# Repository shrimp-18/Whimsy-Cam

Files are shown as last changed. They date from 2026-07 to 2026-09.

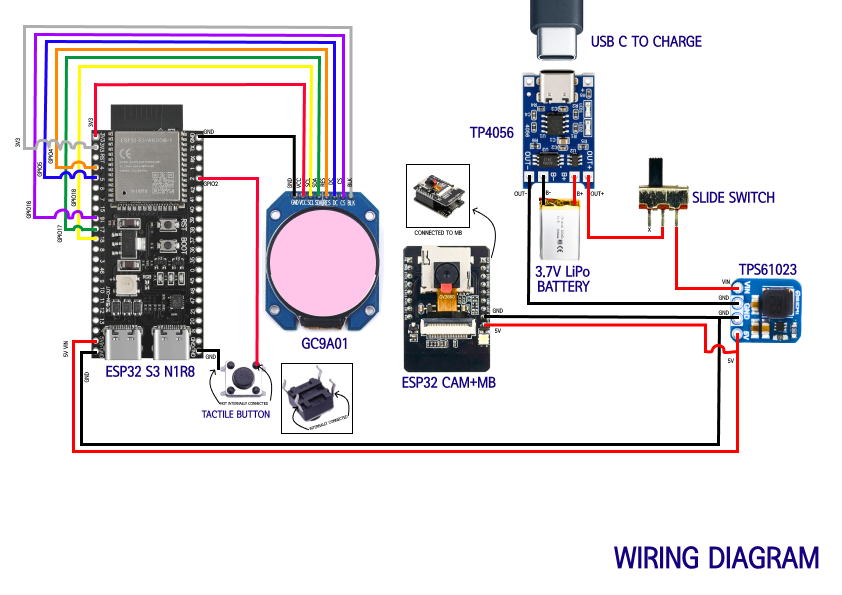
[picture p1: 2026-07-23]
images/wiringdiagram.png

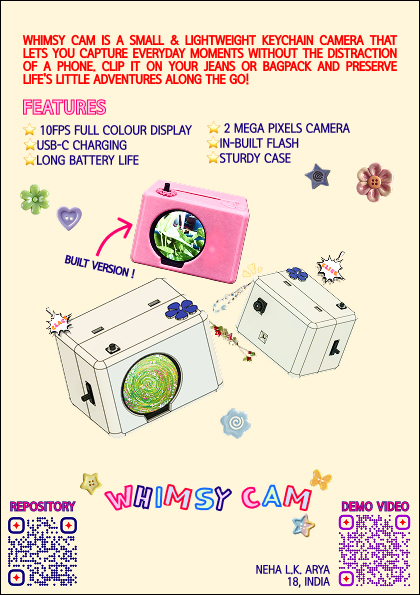
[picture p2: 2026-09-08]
images/zinenew.jpg

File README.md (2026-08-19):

# Whimsy-Cam

WhimsyCam is a small and lightweight keychain camera that lets you capture everyday moments without the distractions of a phone. Clip it to your keys, wear it anywhere, and preserve life's little adventures as they happen!

---

## Demo Video: [Link](https://youtu.be/K1ssOHKLGK0?si=9Yla5hCVhIQCYA2k_)

A5 - 1



**FEATURES** :
+ 2 MEGAPIXEL CAMERA
+ 10FPS FULL COLOUR DISPLAY
+ USB-C CHARGING
+ LONG BATTERY LIFE
+ IN-BUILT FLASH
+ KEYCHAIN/CHARM LANYARD HOLE
+ STURDY CASE
+ EASY SOFTWARE UPDATES

## How to Use:
Whimsy Cam is supa simple to use! Just charge it every once in a while, turn it on and click photos! It comes with s 64gb SD-Card, that means LOTSSSS of photos. It is designed to let you attach cute lanyards and charms to it :3 Keep checking this repository often! If there are updates, you can simply update the firmware of your camera too without touching the hardware or opening anything up. 




---

## Why I made this:
I love photography a lot! And with the recent rise in trend of the kodak keychain disposable camera, I wanted to make something of my own but more durable and long lasting. Whimsy Cam will cost you about 4.5k INR to make, but if you play your cards right(like I did) and use an SD card with lesser storage capacity, you could make it for almost half the price! Which is so much cheaper than whats commercially available, and so much versatile. On the same hardware, you have endless possibilities. In the future I plan to add filters for your photos and improved image quality! And you dont even need to de-assemble your camera to update to the latest software :D, just plug a USB C and hit upload!

---

## How the Camera works:
The Camera is divided into 2 main parts: The Camera Module and the Display Module.
1. The Camera Module:
   The Camera Module is made up of the ESP32 Camera Module with a GC2145 Sensor and an ESP32 Cam MB.It is a TCP(Transmission Control Protocol) Server. It establishes a        WiFi Server and send the captured about 8-10 frames per second to the TCP Client (the display module). When you click a photo, transmission stops for a tiny moment to      capture a high resolution photo and save it as a BMP file to the SD Card. This module gets power from 5V boosted LiPo Battery.
   
3. The Display Module:
   The Display Module is made up of the ESP 32 S3 N1R8 (dev board), a GC9A01 Circual TFT Screen and a tactile button. The ESP 32 S3 is a TCP Client, It recieves frames and    displays them on the screen. When the button is pressed it sends a command to click a photo.This module also gets 5V power from LiPo Battery (after boosting)

The Power Management: 



This wonderful diagram shows the power management of the Camera.
A re-chargable LiPo battery that outputs 3.7V is used. Since the ESP 32 modules need strictly either 3.3V or 5V, I used a TPS61023 Boost Converter to convert 3.7V to a stable 5V. There is a slide switch in between to turn the power on and off. The battery can also be recharged using the T4056 Module, I'm using a Type-C variant. This doesn't really have an over-charge or over-discharge protection yet :( But I'll think about it in future. Since the camera hardware cannot be changed so easily, I'll atleast add a battery level monitor on the camera display to at least protect it from over-discharge. And the green light from the T4056 can be your cue to stop charging hence acting as an over-charge protection.

---

## The Wiring Diagram:
wiringdiagram

## The Case:



----
## Fusion File:
https://a360.co/4wc3e6t

## How to Build:
So did I finally convince you to make your own :3 <br>
1.Procure all components listed in the BOM.<br>

2.Solder Pins to the Display Module.<br>

3.Get Jumper Wireeeess (you'll need 10) and a metre of normal wire. Copy the wiring diagram and connect everything. Try to use the colour-coded wires like I did. Its much easier to understand and remember!<br>

4.Download the code from the firmware folder inside src in this repository. Connect the ESP32 S3 and the Camera module to your computer. Download the Arduino IDE.Compile and upload the code to the respective boards! Now your camera should work!<br>

5.If youre using an SD Card, make sure its formatted to FAT and not ExFAT. Most SD cards by default will be formatted to ExFAT so you need to format them again using your laptop before you plug them into this camera for use. Otherwise your camera wont save photos :( <br>

6.The Fun Part! 3D-print the CAD Files(Front and Back of Case) given in this repository and fix the components in their respective places. Close the case shut! It is a snap fit case. <br>

7.Make cute lanyards and beaded chains to put on the camera so you can carry it around and be a cool kid. Cool because you have a keychain camera and because YOU MADE IT!<br>

YAY DAS IT ITS DONE
idea

---

## Bill of Materials

| S.No. | Product Name | Note | Qty | Cost (INR) | Link |
|---|---|---|-----|---|---|
| 1 | ESP32 S3 N16R8 | | 1 | 1249 | https://robocraze.com/products/7semi-esp32-s3-dev-boardc-1-n8r8-wifi-bluetooth-dual-usb-c-rgb-led |
| 2 | TPS61023 | | 1 | 109 | https://robocraze.com/products/tps61023-3-7a-5v-output-mini-boost-converter-breakout-board-7semi |
| 3 | TP4056 | | 1 | 19 | https://robocraze.com/products/tp4056-battery-charger-c-type-module-with-protection-1 |
| 4 | LiPo Battery | | 1 | 102 | https://robocraze.com/products/witty-fox-160mah-rechargeable-3-7v-lipo-battery |
| 5 | Slide Switch | | 1 | 16 | https://robocraze.com/products/slide-switch-3-pin-2-way-spdt |
| 6 | Tactile Button | 6x6mm | 1 | 29 | https://robocraze.com/products/4-pins-dip-momentary-square-tactile-push-button-switch-10-pieces-6x6x5mm |
| 7 | GC9A01 TFT Screen | | 1 | 422 | https://www.xcluma.com/1-28-inch-round-screen-tft-module-240x240-hd-ips-full |
| 8 | ESP32 Cam Module | GC2145 Sensor | 1 | 699 | https://quartzcomponents.com/products/esp32-camera-development-board-wifi-bluetooth-with-ov2640-camera-module |
| 9 | ESP32 Cam MB | | 1 | 82 | https://quartzcomponents.com/products/esp32-cam-mb-micro-usb-programmer-module-for-esp32-cam-development-board |
| 10 | SD Card | 64GB | 1 | 1605 | https://quartzcomponents.com/products/sandisk-ultra-64gb-microsdxc-class-10-memory-card-140mb-s |
| 11 | 3D Case - Back | | 1 | 95 | https://zbotic.in/product/online-3d-printing-service/ |
| 12 | 3D Case - Front | | 1 | 93 | https://zbotic.in/product/online-3d-printing-service/ |

**Total: 12 items — ₹4520 (~$47 USD)**

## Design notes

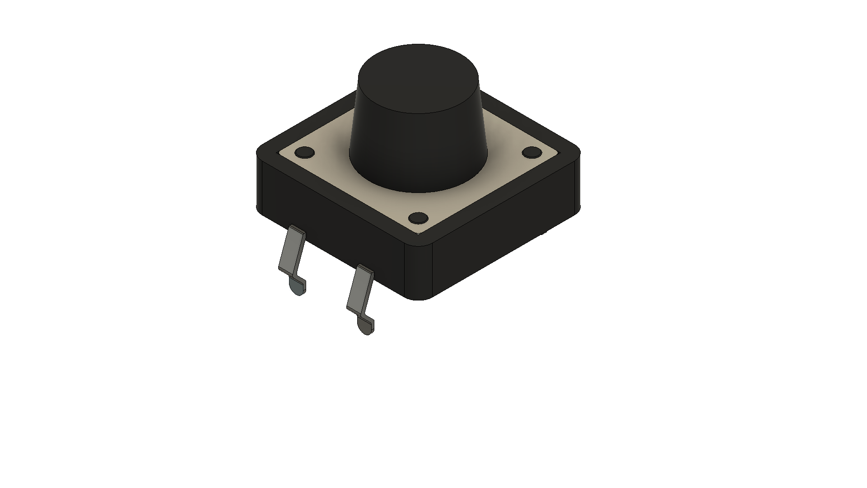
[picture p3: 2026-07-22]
src/cad/assets/12mm x 12mm Tactile switch 3D view.png

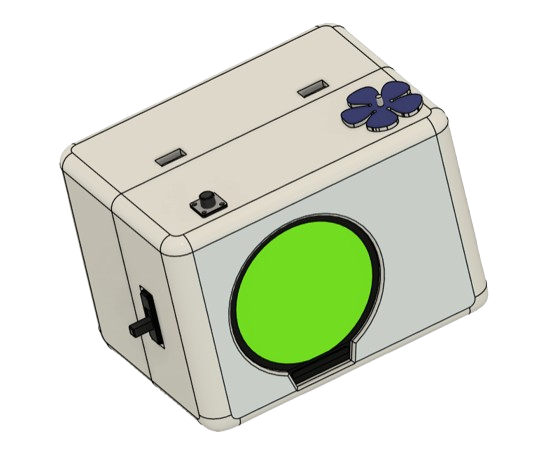
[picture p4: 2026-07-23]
images/camfront.png

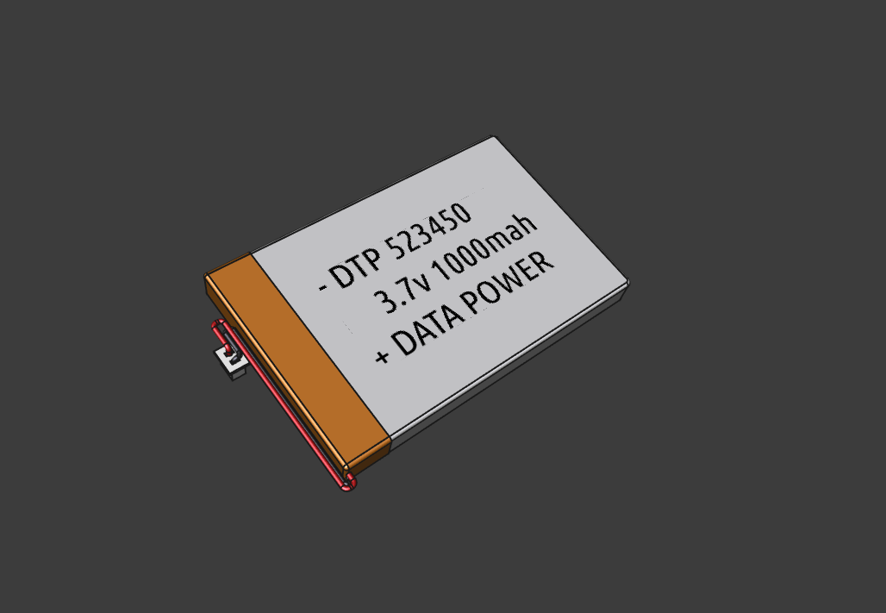
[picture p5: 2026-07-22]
src/cad/assets/bateria_litio.png

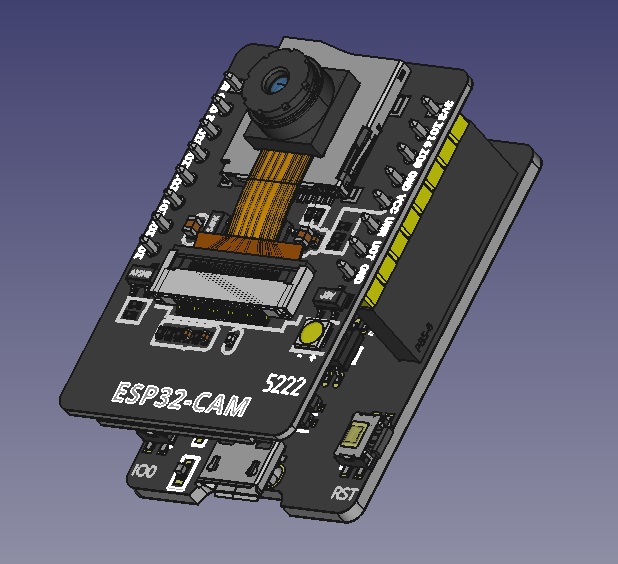
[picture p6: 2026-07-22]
src/cad/assets/View.jpg

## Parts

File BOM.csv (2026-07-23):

S. No. | Product Name | Note | Quantity | Cost | Link
1 | ESP32 S3 N1R8 |  | 1 | INR1249 | https://robocraze.com/products/7semi-esp32-s3-dev-boardc-1-n8r8-wifi-bluetooth-dual-usb-c-rgb-led
2 | TPS61023 |  | 1 | INR109 | https://robocraze.com/products/tps61023-3-7a-5v-output-mini-boost-converter-breakout-board-7semi
3 | TP4056 |  | 1 | INR19 | https://robocraze.com/products/tp4056-battery-charger-c-type-module-with-protection-1
4 | LiPo Battery |  | 1 | INR102 | https://robocraze.com/products/witty-fox-160mah-rechargeable-3-7v-lipo-battery
5 | Slide Switch |  | 1 | INR16 | https://robocraze.com/products/slide-switch-3-pin-2-way-spdt
6 | Tactile Button | 6x6mm | 1 | INR29 | https://robocraze.com/products/4-pins-dip-momentary-square-tactile-push-button-switch-10-pieces-6x6x5mm
7 | GC9A01 TFT Screen |  | 1 | INR422 | https://www.xcluma.com/1-28-inch-round-screen-tft-module-240x240-hd-ips-full
8 | ESP32 Cam Module | GC2145 Sensor | 1 | INR699 | https://quartzcomponents.com/products/esp32-camera-development-board-wifi-bluetooth-with-ov2640-camera-module
9 | ESP32 Cam MB |  | 1 | INR82 | https://quartzcomponents.com/products/esp32-cam-mb-micro-usb-programmer-module-for-esp32-cam-development-board
10 | SD Card | 64GB | 1 | INR1605 | https://quartzcomponents.com/products/sandisk-ultra-64gb-microsdxc-class-10-memory-card-140mb-s
11 | 3D Case-Back |  | 1 | INR95 | https://zbotic.in/product/online-3d-printing-service/
12 | 3D Case-Front |  | 1 | INR93 | https://zbotic.in/product/online-3d-printing-service/
 |  |  | Total: | 10 | INR4520
 |  |  |  |  | ~47USD

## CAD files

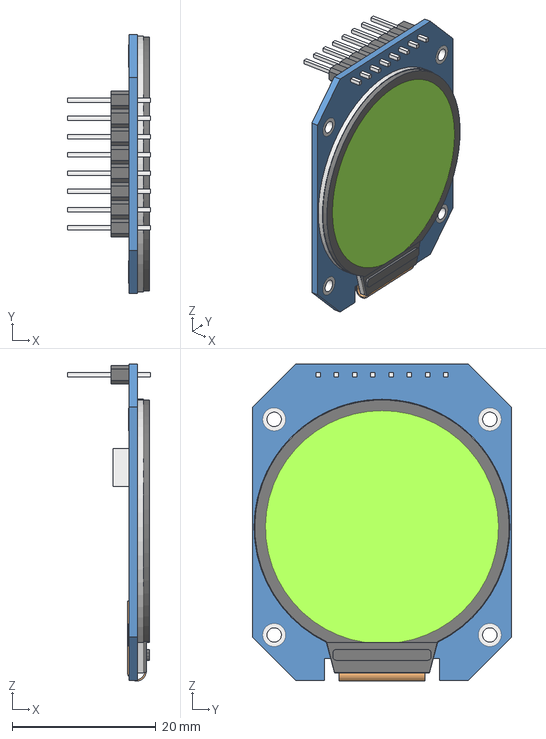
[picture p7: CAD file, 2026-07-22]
src/cad/assets/LCD 1.28 Inch GC9A01.stp
11.5 x 36.0 x 44.1 mm

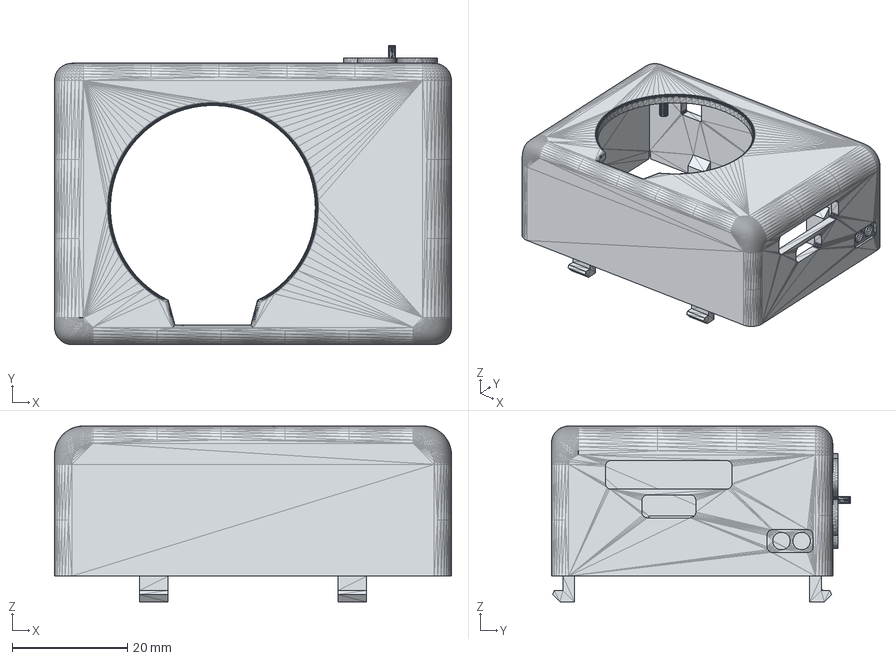
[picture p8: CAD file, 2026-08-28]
src/cad/Front.step
69.0 x 52.0 x 30.6 mm

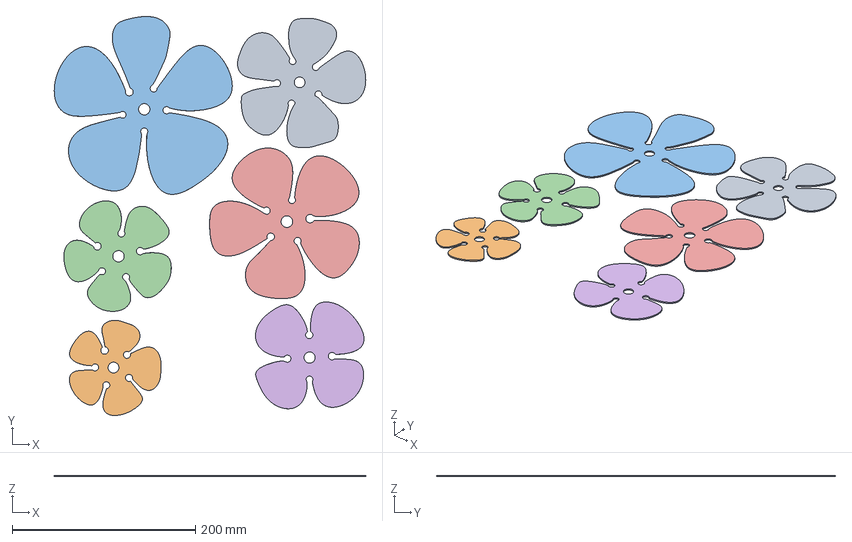
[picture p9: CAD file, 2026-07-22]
src/cad/assets/ROSE PETAL TEMPLATE_STEP.step
340.4 x 435.9 x 1.59 mm

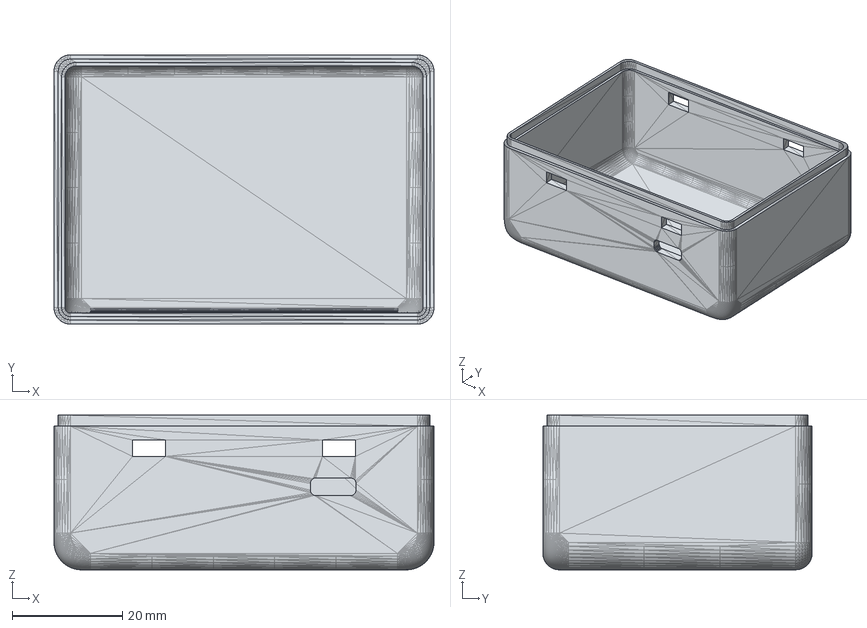
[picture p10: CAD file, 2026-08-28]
src/cad/Back.step
69.0 x 48.9 x 28.1 mm

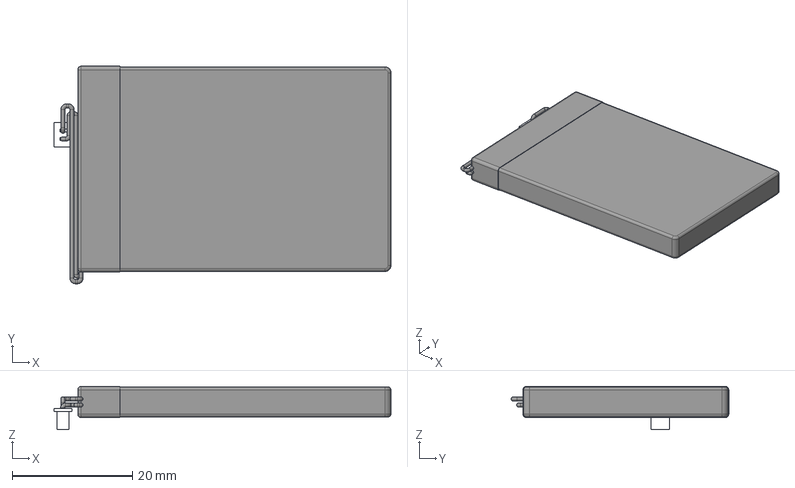
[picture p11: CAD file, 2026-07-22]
src/cad/assets/Litio_523450.step
56.0 x 36.2 x 7.20 mm
Conector

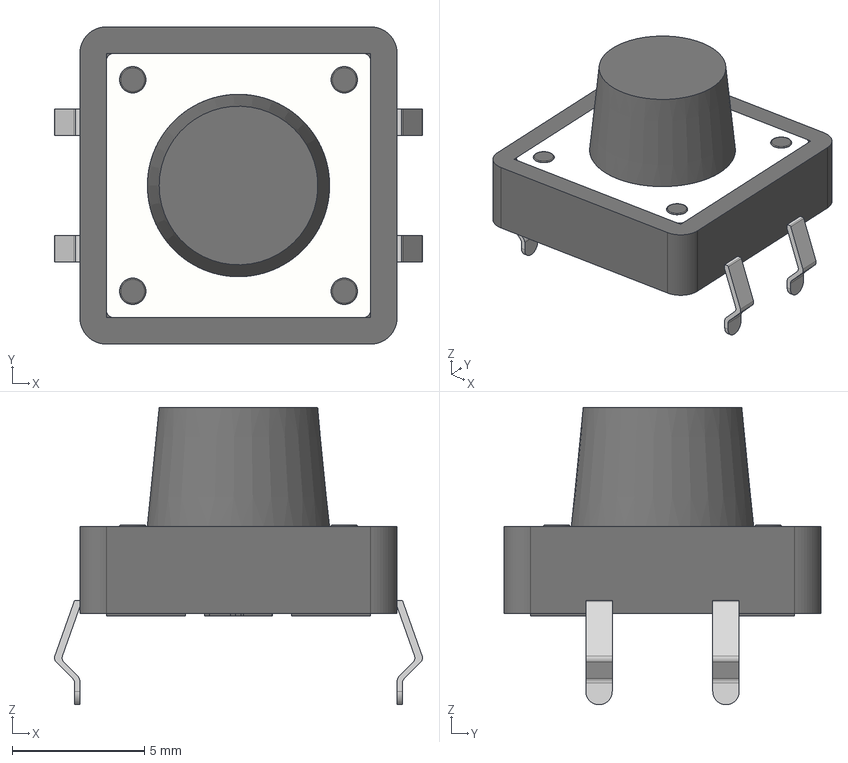
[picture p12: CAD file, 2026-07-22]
src/cad/assets/12mm x 12mm Tactile switch Button.step
13.9 x 12.0 x 11.2 mm
External Case
Steel Plate
Push Button

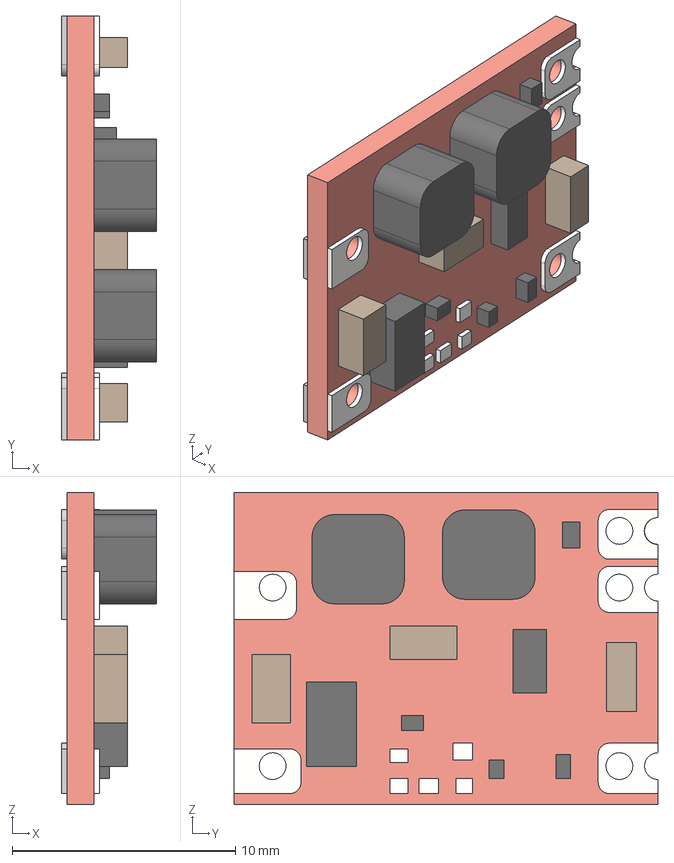
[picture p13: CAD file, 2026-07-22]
src/cad/assets/Auto Buck-Boost DC-DC Converter 12V~0.6A.step
4.25 x 19.0 x 14.0 mm
PCB
Coils
Capacitors
ICS
Resistors
Solder
Terminals

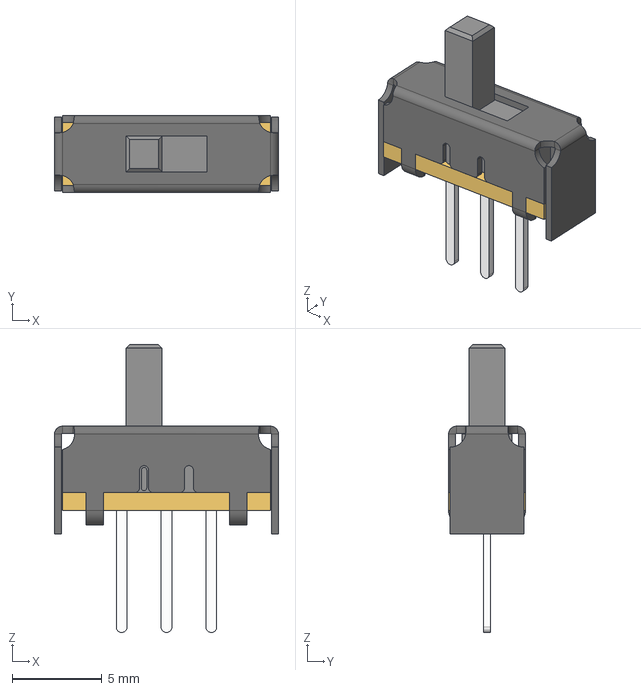
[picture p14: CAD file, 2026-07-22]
src/cad/assets/SLW-116641-3A-RA-S-D.step
12.5 x 4.29 x 16.1 mm

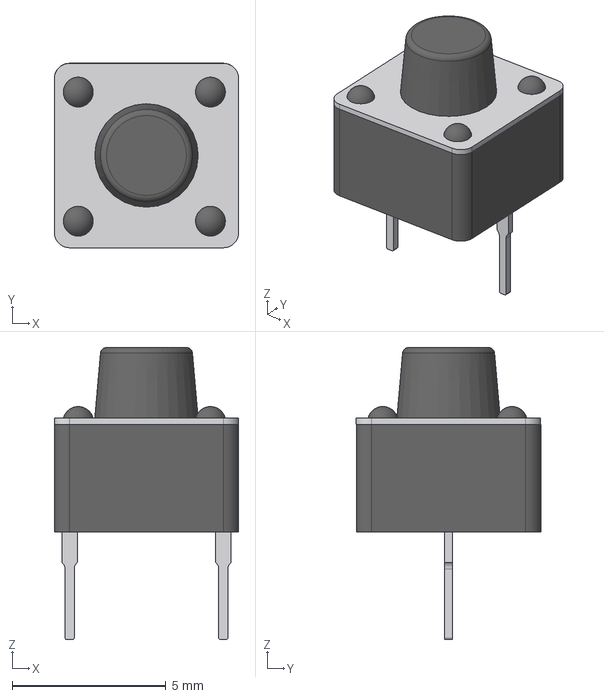
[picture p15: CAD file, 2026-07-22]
src/cad/assets/Reset button.step
6.00 x 6.00 x 9.50 mm

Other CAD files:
src/cad/Back.stl
src/cad/Front.stl

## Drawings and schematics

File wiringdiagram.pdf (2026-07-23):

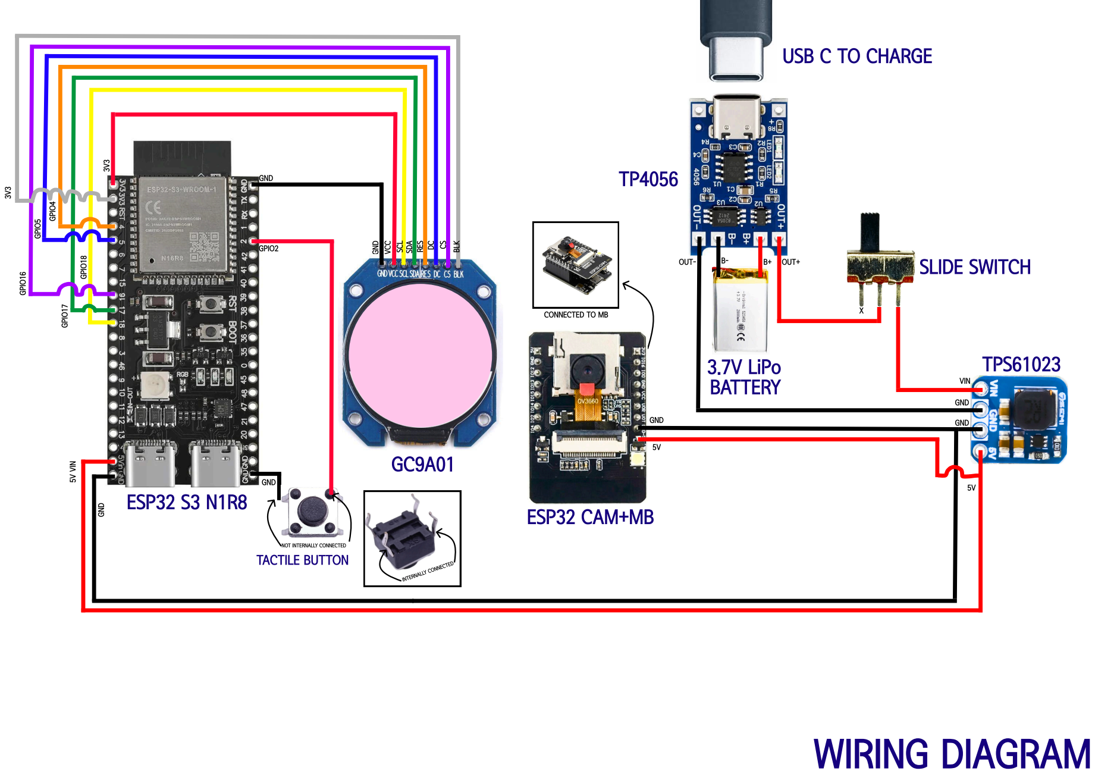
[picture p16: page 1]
GPIO5; GPIO4; GPIO16; GPIO18; GPIO17; GND; GPIO2; VCC; SCL; SDA; RES; BLK; OUT-; OUT+; SLIDE SWITCH; 5V VIN; ESP32 S3 N1R8; TACTILE BUTTON; INTERNALLY CONNECTED; ESP32 CAM+MB; 3.7V LiPo BATTERY; TPS61023; VIN; WIRING DIAGRAM

USB C TO CHARGE

CONNECTED TO MB

NOT INTERNALLY CONNECTED

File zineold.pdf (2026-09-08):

## FEATURES

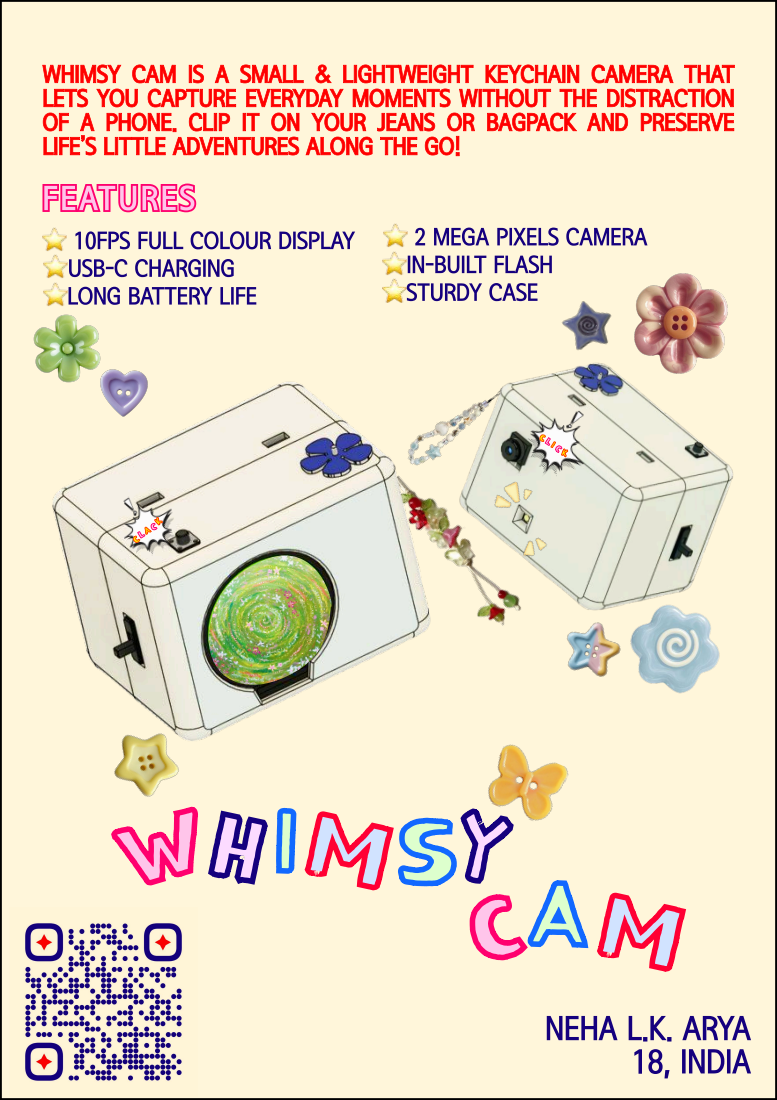
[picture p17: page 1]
⭐ 10FPS FULL COLOUR DISPLAY; ⭐ 2 MEGA PIXELS CAMERA; ⭐USB-C CHARGING; ⭐IN-BUILT FLASH; ⭐LONG BATTERY LIFE; ⭐STURDY CASE; NEHA L.K. ARYA 18, INDIA

WHIMSY CAM IS A SMALL & LIGHTWEIGHT KEYCHAIN CAMERA THAT
LETS YOU CAPTURE EVERYDAY MOMENTS WITHOUT THE DISTRACTION
OF A PHONE. CLIP IT ON YOUR JEANS OR BAGPACK AND PRESERVE LIFE’S LITTLE ADVENTURES ALONG THE GO!

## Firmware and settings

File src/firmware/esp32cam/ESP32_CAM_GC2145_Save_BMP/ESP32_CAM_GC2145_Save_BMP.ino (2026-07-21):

#include <WiFi.h>
#include "esp_camera.h"
#include "FS.h"
#include "SD_MMC.h"

const char* ssid = "WhimsyCam";
const char* password = "12345678";

const int tcpPort = 80;
WiFiServer tcpServer(tcpPort);
WiFiClient tcpClient;

#define PWDN_GPIO_NUM     32
#define RESET_GPIO_NUM    -1
#define XCLK_GPIO_NUM      0
#define SIOD_GPIO_NUM     26
#define SIOC_GPIO_NUM     27
#define Y9_GPIO_NUM       35
#define Y8_GPIO_NUM       34
#define Y7_GPIO_NUM       39
#define Y6_GPIO_NUM       36
#define Y5_GPIO_NUM       21
#define Y4_GPIO_NUM       19
#define Y3_GPIO_NUM       18
#define Y2_GPIO_NUM        5
#define VSYNC_GPIO_NUM    25
#define HREF_GPIO_NUM     23
#define PCLK_GPIO_NUM     22
#define CMD_FRAME    0x01
#define CMD_CAPTURE  0x02
uint8_t *frameBuffer = nullptr;
const size_t frameBufferSize = 240 * 240 * 2;

void sendFrame(WiFiClient &client)
{
    camera_fb_t *fb = esp_camera_fb_get();

    if (!fb)
    {
        client.stop();
        return;
    }

    if (!frameBuffer)
    {
        esp_camera_fb_return(fb);
        client.stop();
        return;
    }

    const int srcWidth = 320;
    const int dstWidth = 240;
    const int height = 240;

    uint16_t *pixels = (uint16_t *)fb->buf;
    uint16_t *out = (uint16_t *)frameBuffer;

    for (int y = 0; y < height; y++)
    {
        memcpy(&out[y * dstWidth], &pixels[y * srcWidth + 40], dstWidth * 2);
    }

    esp_camera_fb_return(fb);
    client.write(frameBuffer, frameBufferSize);
}

bool savePhotoBMP()
{
    camera_fb_t *fb = esp_camera_fb_get();

    if (!fb)
    {
        Serial.println("Capture failed");
        return false;
    }

    static int photoNum = 1;

    char filename[32];
    sprintf(filename, "/IMG%04d.bmp", photoNum++);

    File file = SD_MMC.open(filename, FILE_WRITE);

    if (!file)
    {
        Serial.println("Couldn't create file");
        esp_camera_fb_return(fb);
        return false;
    }

    const int width = 320;
    const int height = 240;
    const uint32_t rowSize = (width * 3 + 3) & ~3;
    const uint32_t imageSize = rowSize * height;
    const uint32_t fileSize = 54 + imageSize;

    uint8_t header[54] = {
        'B','M',
        0,0,0,0,
        0,0,0,0,
        54,0,0,0,
        40,0,0,0,
        0,0,0,0,
        0,0,0,0,
        1,0,
        24,0,
        0,0,0,0,
        0,0,0,0,
        0x13,0x0B,0,0,
        0x13,0x0B,0,0,
        0,0,0,0,
        0,0,0,0
    };

    header[2] = fileSize;
    header[3] = fileSize >> 8;
    header[4] = fileSize >> 16;
    header[5] = fileSize >> 24;

    header[18] = width;
    header[19] = width >> 8;
    header[20] = width >> 16;
    header[21] = width >> 24;

    header[22] = height;
    header[23] = height >> 8;
    header[24] = height >> 16;
    header[25] = height >> 24;

    header[34] = imageSize;
    header[35] = imageSize >> 8;
    header[36] = imageSize >> 16;
    header[37] = imageSize >> 24;

    file.write(header, 54);

    uint16_t *pixels = (uint16_t *)fb->buf;

    uint8_t row[rowSize];

    for (int y = height - 1; y >= 0; y--)
    {
        int idx = 0;

        for (int x = 0; x < width; x++)
        {
            uint16_t p = pixels[y * width + x];
            p = (p >> 8) | (p << 8);

            uint8_t r = ((p >> 11) & 0x1F) << 3;
            uint8_t g = ((p >> 5) & 0x3F) << 2;
            uint8_t b = (p & 0x1F) << 3;

            row[idx++] = b;
            row[idx++] = g;
            row[idx++] = r;
        }

        while (idx < rowSize)
            row[idx++] = 0;

        file.write(row, rowSize);
    }

    file.close();
    esp_camera_fb_return(fb);

    Serial.print("Saved ");
    Serial.println(filename);

    return true;
}

void handleTcp()
{
    if (!tcpClient || !tcpClient.connected())
    {
        tcpClient = tcpServer.available();
        return;
    }

    if (tcpClient.available() > 0)
    {
        uint8_t cmd = tcpClient.read();

        switch (cmd)
        {
            case CMD_FRAME:
                sendFrame(tcpClient);
                break;

            case CMD_CAPTURE:
            {
                bool ok = savePhotoBMP();
                uint8_t resp = ok ? 0x01 : 0x00;
                tcpClient.write(&resp, 1);
                break;
            }

            default:
                tcpClient.stop();
                break;
        }
    }
}

void setup()
{
    Serial.begin(115200);
    delay(2000);

    camera_config_t config;

    config.ledc_channel = LEDC_CHANNEL_0;
    config.ledc_timer = LEDC_TIMER_0;

    config.pin_d0 = Y2_GPIO_NUM;
    config.pin_d1 = Y3_GPIO_NUM;
    config.pin_d2 = Y4_GPIO_NUM;
    config.pin_d3 = Y5_GPIO_NUM;
    config.pin_d4 = Y6_GPIO_NUM;
    config.pin_d5 = Y7_GPIO_NUM;
    config.pin_d6 = Y8_GPIO_NUM;
    config.pin_d7 = Y9_GPIO_NUM;

    config.pin_xclk = XCLK_GPIO_NUM;
    config.pin_pclk = PCLK_GPIO_NUM;
    config.pin_vsync = VSYNC_GPIO_NUM;
    config.pin_href = HREF_GPIO_NUM;

    config.pin_sccb_sda = SIOD_GPIO_NUM;
    config.pin_sccb_scl = SIOC_GPIO_NUM;

    config.pin_pwdn = PWDN_GPIO_NUM;
    config.pin_reset = RESET_GPIO_NUM;

    config.xclk_freq_hz = 20000000;
    config.pixel_format = PIXFORMAT_RGB565;
    config.frame_size = FRAMESIZE_QVGA;
    config.jpeg_quality = 12;
    config.fb_count = 3;

    Serial.println("Initializing camera...");

    esp_err_t err = esp_camera_init(&config);

    if (err != ESP_OK)
    {
        Serial.printf("Camera init failed: 0x%x\n", err);
        while (true)
            delay(1000);
    }

    Serial.println("Camera OK");
    frameBuffer = (uint8_t *)heap_caps_malloc(frameBufferSize, MALLOC_CAP_SPIRAM);
    if (!frameBuffer)
        frameBuffer = (uint8_t *)malloc(frameBufferSize);

    if (!frameBuffer)
        Serial.println("WARNING: frame buffer allocation failed!");

    if (!SD_MMC.begin())
    {
        Serial.println("SD Mount Failed");
        while (true)
            delay(1000);
    }

    Serial.println("SD Ready");

    sensor_t *s = esp_camera_sensor_get();

    s->set_whitebal(s, 1);
    s->set_awb_gain(s, 1);
    s->set_exposure_ctrl(s, 1);
    s->set_gain_ctrl(s, 1);

    s->set_brightness(s, 1);
    s->set_contrast(s, 1);
    s->set_saturation(s, 2);

    WiFi.mode(WIFI_AP);

    Serial.println("Starting AP...");

    WiFi.softAP(ssid, password);
    WiFi.setSleep(false);

    Serial.print("Camera IP: ");
    Serial.println(WiFi.softAPIP());

    tcpServer.begin();
    tcpServer.setNoDelay(true);

    savePhotoBMP();

    Serial.println("TCP server started");
    Serial.println("Ready!");
}

void loop()
{
    handleTcp();
}

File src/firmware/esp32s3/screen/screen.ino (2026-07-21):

#define LGFX_USE_V1
#include <LovyanGFX.hpp>
#include <WiFi.h>

const char* ssid = "WhimsyCam";
const char* password = "12345678";
const int buttonPin = 2;
const char* host = "192.168.4.1";
const int port = 80;

// Must match the server's protocol.
#define CMD_FRAME    0x01
#define CMD_CAPTURE  0x02

bool takePhoto = false;
WiFiClient client;

class LGFX : public lgfx::LGFX_Device
{
  lgfx::Panel_GC9A01 _panel;
  lgfx::Bus_SPI _bus;
public:
  LGFX(void)
  {
    {
      auto cfg = _bus.config();
      cfg.spi_host = SPI2_HOST;
      cfg.spi_mode = 0;
      cfg.freq_write = 80000000;
      cfg.freq_read  = 16000000;
      cfg.pin_sclk = 18;
      cfg.pin_mosi = 17;
      cfg.pin_miso = -1;
      cfg.pin_dc   = 5;
      _bus.config(cfg);
      _panel.setBus(&_bus);
    }
    {
      auto cfg = _panel.config();
      cfg.pin_cs           = 16;
      cfg.pin_rst          = 4;
      cfg.pin_busy         = -1;
      cfg.memory_width     = 240;
      cfg.memory_height    = 240;
      cfg.panel_width      = 240;
      cfg.panel_height     = 240;
      cfg.offset_x         = 0;
      cfg.offset_y         = 0;
      cfg.offset_rotation  = 0;
      cfg.dummy_read_pixel = 8;
      cfg.dummy_read_bits  = 1;
      cfg.readable         = false;
      cfg.invert           = true;
      cfg.rgb_order        = false;
      cfg.dlen_16bit       = false;
      cfg.bus_shared       = false;
      _panel.config(cfg);
    }
    setPanel(&_panel);
  }
};

LGFX tft;

// Whole-frame buffer (240x240 RGB565 = 115200 bytes). Reading and
// pushing the full frame in one shot instead of 15 small chunks cuts
// per-call overhead on both the network read and the SPI push.
uint16_t frameBuf[240 * 240];
const size_t frameBufBytes = sizeof(frameBuf);

// Connects once and stays connected. Only reconnects if the socket
// has actually dropped - this is what avoids paying for a fresh TCP
// handshake on every single frame.
bool ensureConnected()
{
    if (client.connected())
        return true;

    Serial.println("Connecting...");
    if (!client.connect(host, port))
    {
        Serial.println("Failed");
        return false;
    }

    client.setNoDelay(true); // disable Nagle - cuts per-write latency
    return true;
}

// Blocks until exactly `len` bytes have been read into buf, or the
// connection drops.
bool readExact(uint8_t *buf, size_t len)
{
    size_t got = 0;
    while (got < len)
    {
        if (!client.connected())
            return false;

        int n = client.read(buf + got, len - got);
        if (n > 0)
            got += n;
    }
    return true;
}

bool requestFrame()
{
    uint8_t cmd = CMD_FRAME;
    client.write(&cmd, 1);

    // One big read instead of 15 chunked ones.
    if (!readExact((uint8_t *)frameBuf, frameBufBytes))
        return false;

    // One big SPI push instead of 15 chunked ones.
    tft.startWrite();
    tft.pushImage(0, 0, 240, 240, frameBuf);
    tft.endWrite();
    return true;
}

void capturePhoto()
{
    uint8_t cmd = CMD_CAPTURE;
    client.write(&cmd, 1);

    uint8_t resp = 0x00;
    if (readExact(&resp, 1) && resp == 0x01)
        Serial.println("Photo saved!");
    else
        Serial.println("Capture failed");
}

void setup()
{
    Serial.begin(115200);
    pinMode(buttonPin, INPUT_PULLUP);
    tft.init();
    tft.setSwapBytes(false);
    tft.setRotation(0);
    tft.fillScreen(TFT_BLACK);
    tft.setTextColor(TFT_WHITE);
    tft.drawString("Connecting...", 40, 100);

    WiFi.begin(ssid, password);
    while (WiFi.status() != WL_CONNECTED)
    {
        delay(500);
        Serial.print(".");
    }
    Serial.println();
    Serial.println("Connected!");
    WiFi.setSleep(false);
    tft.fillScreen(TFT_GREEN);
    tft.drawString("WiFi OK", 60, 110);
}

void loop()
{
    static bool lastState = HIGH;
    bool state = digitalRead(buttonPin);
    if (lastState == HIGH && state == LOW)
        takePhoto = true;
    lastState = state;

    if (!ensureConnected())
    {
        delay(500);
        return;
    }

    if (takePhoto)
    {
        takePhoto = false;
        Serial.println("Taking photo...");
        capturePhoto();
    }

    if (!requestFrame())
    {
        Serial.println("Frame read failed, reconnecting...");
        client.stop();
        return;
    }
}

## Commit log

2026-07-19 screen and camera code files, made kicad files
    [WhimsyCam_KiCad.kicad_pcb, WhimsyCam_KiCad.kicad_sch]
2026-07-19 wifi and organised code files
    [WhimsyCam_KiCad.kicad_pcb, WhimsyCam_KiCad.kicad_sch]
2026-07-20 camera and screen work together
2026-07-21 made schematic
    [WhimsyCam_KiCad.kicad_sch]
2026-07-22 bom and cad
    [12mm x 12mm Tactile switch Button.step, Auto Buck-Boost DC-DC Converter 12V~0.6A.step, BOM.csv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]
2026-07-23 zine and wiring diagram
    [BOM.csv, WhimsyCam_KiCad.kicad_pcb, WhimsyCam_KiCad.kicad_sch]
2026-08-28 added step files
    [Back.step, Front.step]
